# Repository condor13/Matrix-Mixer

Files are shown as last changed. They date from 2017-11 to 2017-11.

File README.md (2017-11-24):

# Matrix-Mixer rev.02 - IN PRODUCTION!

Welcome to the Matrix-Mixer wiki! Matrix mixer is a device that routes multiple input audio signals to multiple outputs.
It employs level controls to determine how much of each input is going to each output. The number of individual controls 
is the number of inputs witch is six multiplied by the number of outputs witch is six so (complex math) 36 controls.
It outputs mono, converts synth level signals to pro line level (+4dBu). LED`s for input clipping.

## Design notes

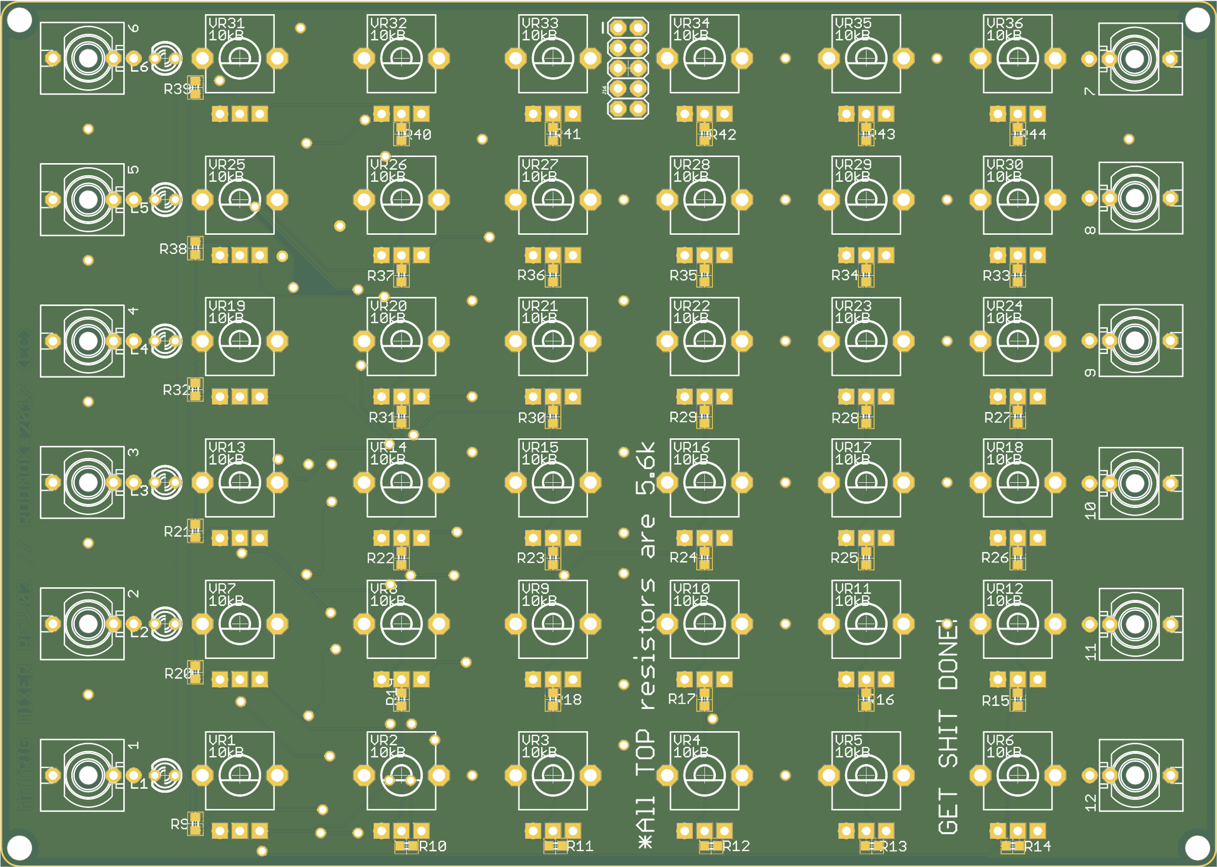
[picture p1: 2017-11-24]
GRB PCB.png_Combined_Top.png

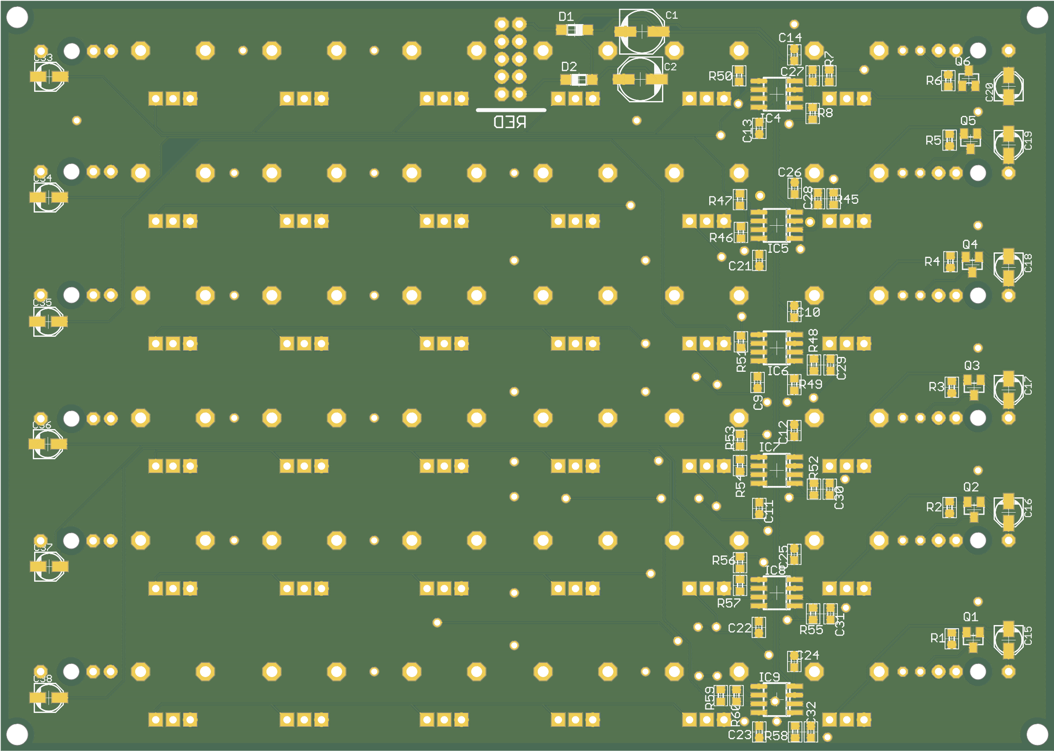
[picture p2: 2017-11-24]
GRB PCB.png_Combined_Bottom.png

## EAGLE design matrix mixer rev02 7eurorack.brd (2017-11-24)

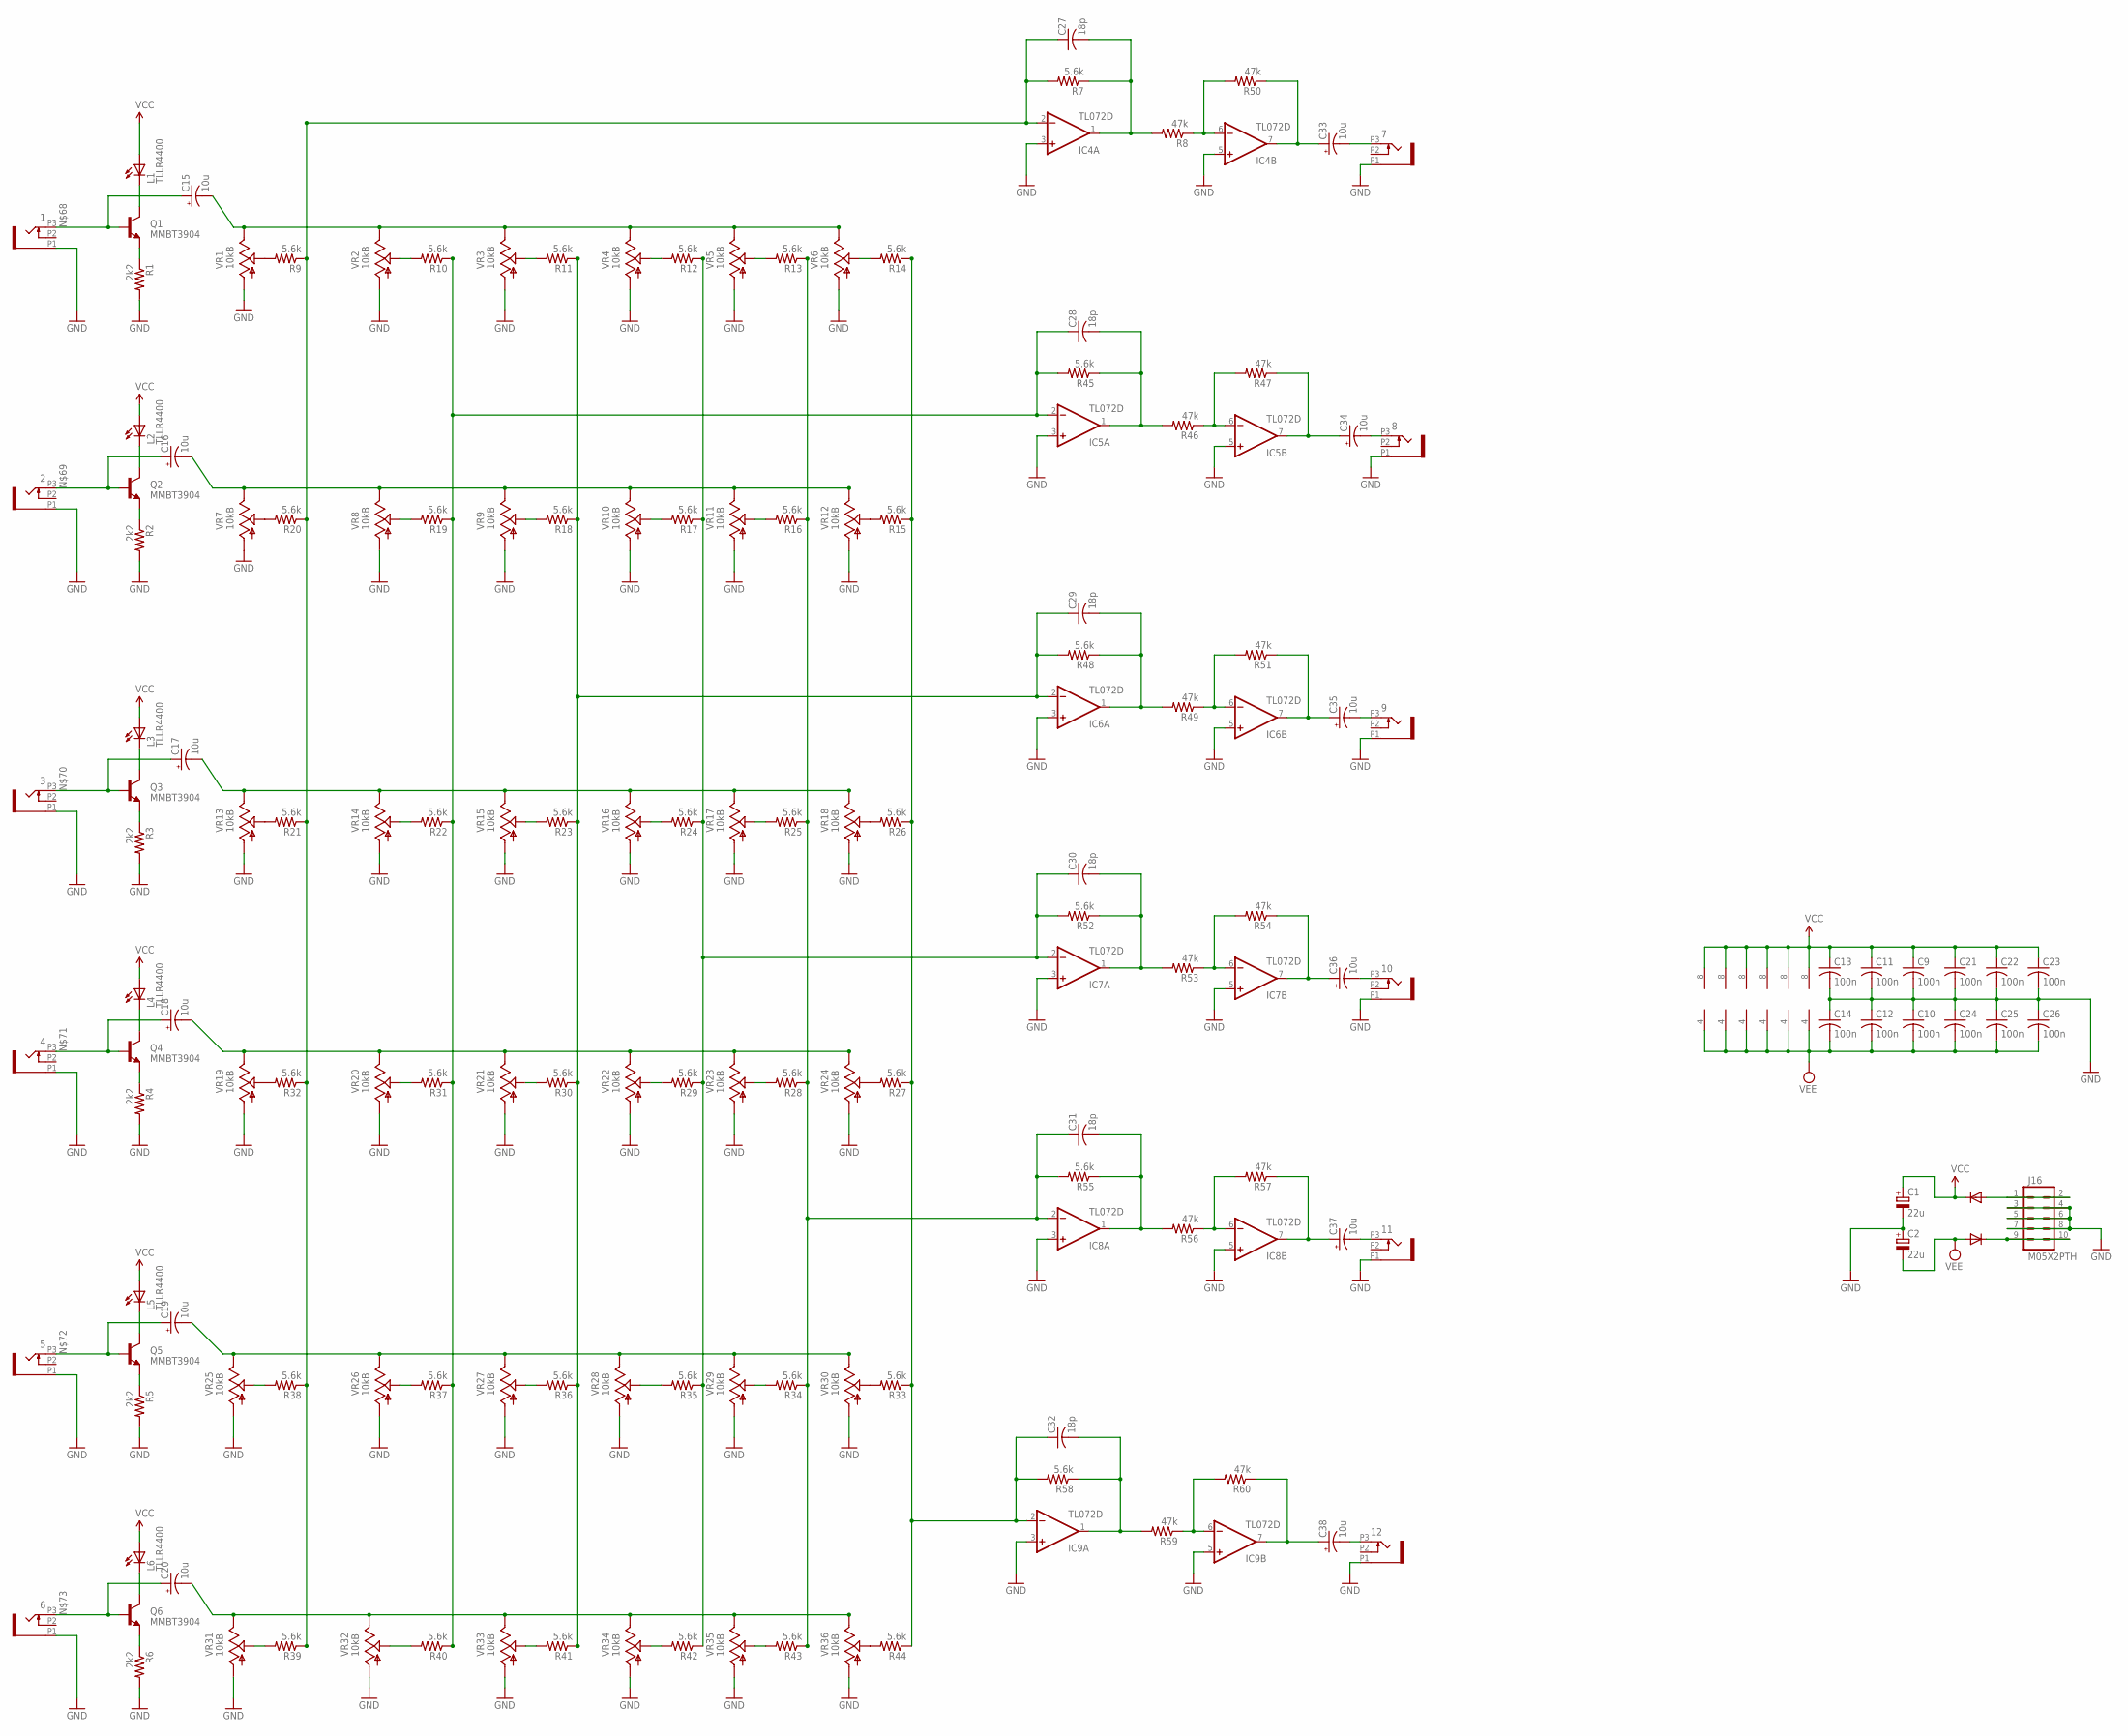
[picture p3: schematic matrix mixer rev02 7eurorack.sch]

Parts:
1, 2, 3, 4, 5, 6, 7, 8, 9, 10, 11, 12: PJ301_THONKICONN6; WQP_PJ_301M6
C1, C2: 22u; PANASONIC_D
C9, C10, C11, C12, C13, C14, C21, C22, C23, C24, C25, C26: 100n; C0603
C15, C16, C17, C18, C19, C20, C33, C34, C35, C36, C37, C38: 10u; PANASONIC_B
C27, C28, C29, C30, C31, C32: 18p; C0603
D1, D2: 1N5819HW; SOD123
IC4, IC5, IC6, IC7, IC8, IC9: TL072D; SO08
J16: M05X2PTH; AVR_ICSP
L1, L2, L3, L4, L5, L6: TLLR4400; LED3MM
Q1, Q2, Q3, Q4, Q5, Q6: MMBT3904; SOT23-BEC
R1, R2, R3, R4, R5, R6: 2k2; R0603
R7, R9, R10, R11, R12, R13, R14, R15, R16, R17, R18, R19, R20, R21, R22, R23, R24, R25, R26, R27, R28, R29, R30, R31, R32, R33, R34, R35, R36, R37, R38, R39, R40, R41, R42, R43, R44, R45, R48, R52, R55, R58: 5.6k; R0603
R8, R46, R47, R49, R50, R51, R53, R54, R56, R57, R59, R60: 47k; R0603
VR1, VR2, VR3, VR4, VR5, VR6, VR7, VR8, VR9, VR10, VR11, VR12, VR13, VR14, VR15, VR16, VR17, VR18, VR19, VR20, VR21, VR22, VR23, VR24, VR25, VR26, VR27, VR28, VR29, VR30, VR31, VR32, VR33, VR34, VR35, VR36: 10kB; ALPS_POT_VERTICAL_PS

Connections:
GND: 1.P1 (1), 2.P1 (1), 3.P1 (1), 4.P1 (1), 5.P1 (1), 6.P1 (1), 7.P1 (1), 8.P1 (1), 9.P1 (1), 10.P1 (1), 11.P1 (1), 12.P1 (1), C1.-, C2.+, C9.2, C10.1, C11.2, C12.1, C13.2, C14.1, C21.2, C22.2, C23.2, C24.1, C25.1, C26.1, IC4.3 (+IN), IC4.5 (+IN), IC5.3 (+IN), IC5.5 (+IN), IC6.3 (+IN), IC6.5 (+IN), IC7.3 (+IN), IC7.5 (+IN), IC8.3 (+IN), IC8.5 (+IN), IC9.3 (+IN), IC9.5 (+IN), J16.3, J16.4, J16.5, J16.6, J16.7, J16.8, R1.2, R2.2, R3.2, R4.2, R5.2, R6.2, VR1.P$3 (A), VR2.P$3 (A), VR3.P$3 (A), VR4.P$3 (A), VR5.P$3 (A), VR6.P$3 (A), VR7.P$3 (A), VR8.P$3 (A), VR9.P$3 (A), VR10.P$3 (A), VR11.P$3 (A), VR12.P$3 (A), VR13.P$3 (A), VR14.P$3 (A), VR15.P$3 (A), VR16.P$3 (A), VR17.P$3 (A), VR18.P$3 (A), VR19.P$3 (A), VR20.P$3 (A), VR21.P$3 (A), VR22.P$3 (A), VR23.P$3 (A), VR24.P$3 (A), VR25.P$3 (A), VR26.P$3 (A), VR27.P$3 (A), VR28.P$3 (A), VR29.P$3 (A), VR30.P$3 (A), VR31.P$3 (A), VR32.P$3 (A), VR33.P$3 (A), VR34.P$3 (A), VR35.P$3 (A), VR36.P$3 (A)
INPUT_1: C15.-, VR1.P$1 (E), VR2.P$1 (E), VR3.P$1 (E), VR4.P$1 (E), VR5.P$1 (E), VR6.P$1 (E)
INPUT_2: C16.-, VR7.P$1 (E), VR8.P$1 (E), VR9.P$1 (E), VR10.P$1 (E), VR11.P$1 (E), VR12.P$1 (E)
INPUT_3: C17.-, VR13.P$1 (E), VR14.P$1 (E), VR15.P$1 (E), VR16.P$1 (E), VR17.P$1 (E), VR18.P$1 (E)
INPUT_4: C18.-, VR19.P$1 (E), VR20.P$1 (E), VR21.P$1 (E), VR22.P$1 (E), VR23.P$1 (E), VR24.P$1 (E)
INPUT_5: C19.-, VR25.P$1 (E), VR26.P$1 (E), VR27.P$1 (E), VR28.P$1 (E), VR29.P$1 (E), VR30.P$1 (E)
INPUT_6: C20.-, VR31.P$1 (E), VR32.P$1 (E), VR33.P$1 (E), VR34.P$1 (E), VR35.P$1 (E), VR36.P$1 (E)
unnamed: R9.2, VR1.P$2 (S)
unnamed: Q2.E, R2.1
unnamed: Q1.E, R1.1
unnamed: R10.2, VR2.P$2 (S)
unnamed: R11.2, VR3.P$2 (S)
unnamed: 12.P3 (3), C38.-
unnamed: L2.K (C), Q2.C
unnamed: L1.K (C), Q1.C
unnamed: R12.2, VR4.P$2 (S)
unnamed: R13.2, VR5.P$2 (S)
unnamed: R14.2, VR6.P$2 (S)
unnamed: L4.K (C), Q4.C
unnamed: R15.2, VR12.P$2 (S)
unnamed: R16.2, VR11.P$2 (S)
unnamed: L3.K (C), Q3.C
unnamed: R17.2, VR10.P$2 (S)
unnamed: R18.2, VR9.P$2 (S)
unnamed: R19.2, VR8.P$2 (S)
unnamed: R20.2, VR7.P$2 (S)
unnamed: Q4.E, R4.1
unnamed: R21.2, VR13.P$2 (S)
unnamed: R22.2, VR14.P$2 (S)
unnamed: R23.2, VR15.P$2 (S)
unnamed: R24.2, VR16.P$2 (S)
unnamed: R25.2, VR17.P$2 (S)
unnamed: R26.2, VR18.P$2 (S)
unnamed: Q3.E, R3.1
unnamed: R27.2, VR24.P$2 (S)
unnamed: L6.K (C), Q6.C
unnamed: L5.K (C), Q5.C
unnamed: Q6.E, R6.1
unnamed: Q5.E, R5.1
unnamed: 11.P3 (3), C37.-
unnamed: 10.P3 (3), C36.-
unnamed: 9.P3 (3), C35.-
unnamed: 8.P3 (3), C34.-
unnamed: 7.P3 (3), C33.-
unnamed: R28.2, VR23.P$2 (S)
unnamed: R29.2, VR22.P$2 (S)
unnamed: R30.2, VR21.P$2 (S)
unnamed: R31.2, VR20.P$2 (S)
unnamed: R32.2, VR19.P$2 (S)
unnamed: R33.2, VR30.P$2 (S)
unnamed: D1.A, J16.1, J16.2
unnamed: R34.2, VR29.P$2 (S)
unnamed: D2.C, J16.9, J16.10
unnamed: R35.2, VR28.P$2 (S)
unnamed: R36.2, VR27.P$2 (S)
unnamed: R37.2, VR26.P$2 (S)
unnamed: R38.2, VR25.P$2 (S)
unnamed: R39.2, VR31.P$2 (S)
unnamed: R40.2, VR32.P$2 (S)
unnamed: R41.2, VR33.P$2 (S)
unnamed: R42.2, VR34.P$2 (S)
unnamed: R43.2, VR35.P$2 (S)
unnamed: R44.2, VR36.P$2 (S)
unnamed: C27.1, IC4.2 (-IN), R7.2, R9.1, R20.1, R21.1, R32.1, R38.1, R39.1
unnamed: C28.1, IC5.2 (-IN), R10.1, R19.1, R22.1, R31.1, R37.1, R40.1, R45.2
unnamed: C29.1, IC6.2 (-IN), R11.1, R18.1, R23.1, R30.1, R36.1, R41.1, R48.2
unnamed: C30.1, IC7.2 (-IN), R12.1, R17.1, R24.1, R29.1, R35.1, R42.1, R52.2
unnamed: C31.1, IC8.2 (-IN), R13.1, R16.1, R25.1, R28.1, R34.1, R43.1, R55.2
unnamed: C32.1, IC9.2 (-IN), R14.1, R15.1, R26.1, R27.1, R33.1, R44.1, R58.2
unnamed: 1.P3 (3), C15.+, Q1.B
unnamed: 2.P3 (3), C16.+, Q2.B
unnamed: 3.P3 (3), C17.+, Q3.B
unnamed: 4.P3 (3), C18.+, Q4.B
unnamed: 5.P3 (3), C19.+, Q5.B
unnamed: 6.P3 (3), C20.+, Q6.B
unnamed: C27.2, IC4.1 (OUT), R7.1, R8.2
unnamed: IC4.6 (-IN), R8.1, R50.2
unnamed: C33.+, IC4.7 (OUT), R50.1
unnamed: C28.2, IC5.1 (OUT), R45.1, R46.2
unnamed: IC5.6 (-IN), R46.1, R47.2
unnamed: C34.+, IC5.7 (OUT), R47.1
unnamed: C29.2, IC6.1 (OUT), R48.1, R49.2
unnamed: IC6.6 (-IN), R49.1, R51.2
unnamed: C35.+, IC6.7 (OUT), R51.1
unnamed: C30.2, IC7.1 (OUT), R52.1, R53.2
unnamed: IC7.6 (-IN), R53.1, R54.2
unnamed: C36.+, IC7.7 (OUT), R54.1
unnamed: C31.2, IC8.1 (OUT), R55.1, R56.2
unnamed: IC8.6 (-IN), R56.1, R57.2
unnamed: C37.+, IC8.7 (OUT), R57.1
unnamed: C32.2, IC9.1 (OUT), R58.1, R59.2
unnamed: IC9.6 (-IN), R59.1, R60.2
unnamed: C38.+, IC9.7 (OUT), R60.1
VCC: C1.+, C9.1, C11.1, C13.1, C21.1, C22.1, C23.1, D1.C, IC4.8 (V+), IC5.8 (V+), IC6.8 (V+), IC7.8 (V+), IC8.8 (V+), IC9.8 (V+), L1.A, L2.A, L3.A, L4.A, L5.A, L6.A
VEE: C2.-, C10.2, C12.2, C14.2, C24.2, C25.2, C26.2, D2.A, IC4.4 (V-), IC5.4 (V-), IC6.4 (V-), IC7.4 (V-), IC8.4 (V-), IC9.4 (V-)

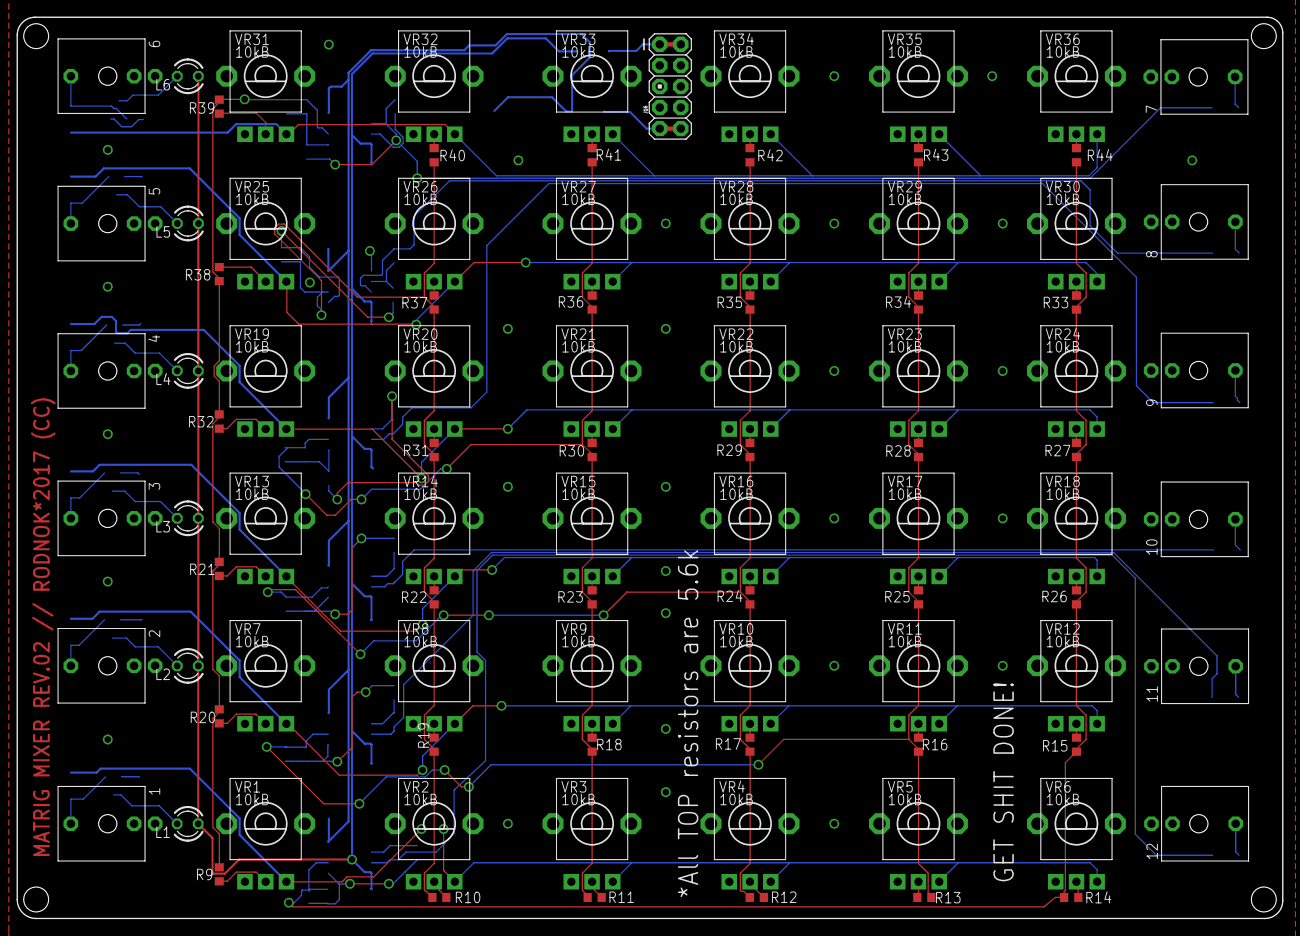
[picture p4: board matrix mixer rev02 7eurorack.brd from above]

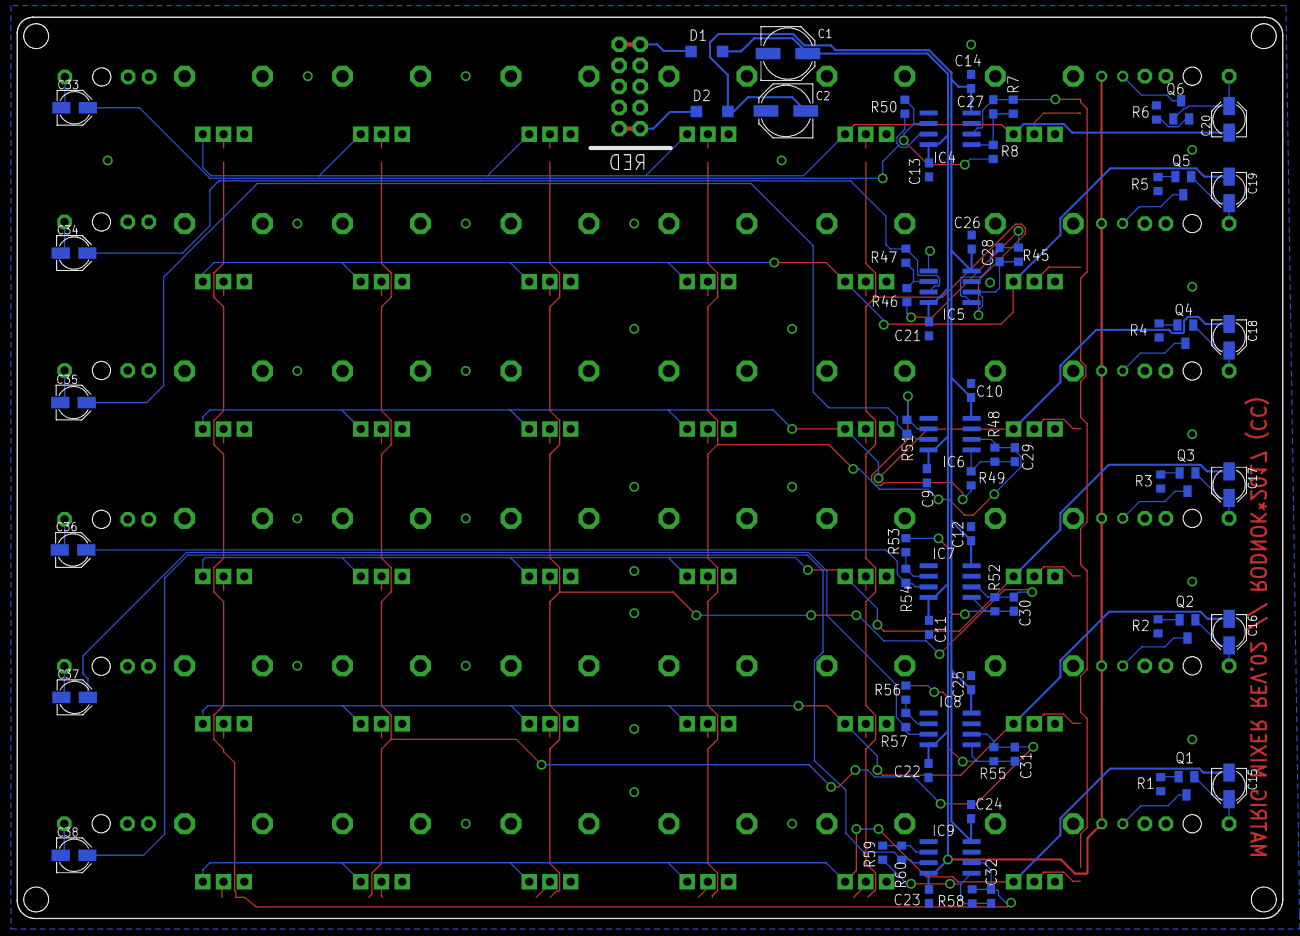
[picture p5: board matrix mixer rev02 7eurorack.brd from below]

Board: 2 copper layers, 152.7 x 108.7 mm, 161 parts (70 on the bottom side), 95 nets.

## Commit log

2017-09-29 Add files via upload
    Modfied the board size and via size.
    [matrix mixer 7eurorack.GBL, matrix mixer 7eurorack.GBO, matrix mixer 7eurorack.GBS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]
2017-11-24 rev.02 and Panel
    [matrix mixer rev02 7eurorack-panel.brd, matrix mixer rev02 7eurorack-panel.sch, matrix mixer rev02 7eurorack.brd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]
